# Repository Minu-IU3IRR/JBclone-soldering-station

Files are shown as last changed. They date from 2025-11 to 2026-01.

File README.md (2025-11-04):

# DIY Multi-Channel JBC-Compatible Soldering Station

A high-performance open hardware soldering station designed to support **JBC and other thermocouple-based soldering tips**.  
This project aims to deliver professional-grade thermal control and user experience at a fraction of the cost of a commercial JBC system.

---

## Overview

The system provides **multi-channel support**, each with independent temperature feedback loops based on PID control.  
It includes modular PCB designs, 3D-printable case that fits in a standard 200x200mm 3d printer, STM32F103 microcontroller, Nextion HMI interface

**Key features:**
- Multi-channel indipendent temperature control
- Compatible with any arbitrary tip, JBC or otherwise, as long as it uses a thermocouple
- PID temperature control with zero cross switching
- external EEprom stored calcibration and tuning  
- Nextion-based HMI for user interaction
- Fully open-source hardware and firmware

---
## Firmware Architecture

The firmware is structured into modules:

| Module | Description |
|---|---|
| **Heater/** | PID controller, temperature processing, and power control routines |
| **EEprom/** | Persistent storage for calibration and configuration |
| **Hardware_definition/** | Board pin mapping, timing constants, and I/O configuration |
| **display/** | Nextion display communication handler |
| **hartbeat/** | System heartbeat and status indicator |
| **Parser/** | Command parser for serial/HMI communication |

**PID Control:**  
The controller continuously adjusts heater drive based on thermocouple feedback.  
Parameters `Kp`, `Ki`, and `Kd` can be tuned at runtime through serial commands or tuning software.

**EEPROM Configuration:**  
All configuration data (tip profiles, PID tuning, calibration) is saved in EEPROM.  
On startup, the station loads the saved configuration automatically.

---

## Hardware Assembly

1. **PCBs:**  
   Fabricate the `mainboard` and `daughterboard` Gerbers (found under `/production/`).
2. **Mechanical design:**  
   View or download the CAD model on Onshape:  
   👉 [Onshape Assembly Model](https://cad.onshape.com/documents/a679f571d3dbe280f604253c/w/8a053e0b812f1b7821749418/e/78f31934af3d4bb4e1cbee4a)
3. **Transformer:**  
   Follow winding and connection details from the `transformer/` folder or pick a closely matched one (MUST HAVE INDIPENDENT WINDINGS FOR EACH OUTPUT)

---

## 🖥️ HMI Setup

1. Open `NX3224T024_hmi.HMI` in **Nextion Editor**.
2. Connect the display to the mainboard’s UART (`Serial1`, 115200 bps).
3. Upload the `.tft` file to the screen via SD card or serial upload or upload via SD-card, check Nextion documentation
5. The interface provides:
   - Channel selection  
   - Temperature setpoint entry  
   - Live tip temperature display

---

## Software Build

1. **Install [PlatformIO](https://platformio.org/).**
2. Open `Software/JBclone Firmware/` in VS Code.
3. Connect your STM32 board using an ST-link dongle.
4. Build and upload:
   ```bash
   pio run --target upload
   ```
5. The firmware will automatically initialize EEPROM and start monitoring the heater.

---

## Calibration & Tuning

- Refer to `cal and tuning table.ods` for measured offsets and recommended PID coefficients.  
- Store calibration through serial commands or via tuning software.  
- EEPROM ensures retention between power cycles.

---

## License

**Hardware (PCBs, transformer, mechanical design):**  
Released under the [CERN-OHL-P v2 License](https://ohwr.org/project/cernohl/wikis/Documents/CERN-OHL-version-2).  
You are free to use, modify, and distribute, provided attribution to the original project is maintained.  

**Firmware and software:**  
Released under the [MIT License](https://opensource.org/licenses/MIT).  

All content is provided **as-is** without any warranty or liability.  
Please include a reference to this repository when sharing or modifying the design.

---

## Credits

Project designed and developed by Manuel Minutello.  
Hardware and firmware are open for modification and improvement by the community.

---

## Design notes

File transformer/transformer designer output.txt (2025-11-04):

Transformer design
Sn (VA)                                  : 150.00
Efficiency (%)                           : 90.06
Total Power Loss (W)                     : 16.55
Total mass (kg)                          : 4.66
Core
|-design frequency (Hz):                 : 50.00
|-thickness (mm):                        : 55.00
|-mass (kg):                             : 4.04
|-Pfe (W):                               : 0.81
|-cross section area (cm^2):             : 22.00
|-V/turn:                                : 0.49
============================================================
Upper bobin
|-Primary Winding
|  |-Vn (V):                                  : 230.19
|  |-In (A):                                  : 0.65
|  |-Current density (A/mm^2):                : 2.09
|  |-Pcu (W):                                 : 2.30
|  |-N:                                       : 471
|  |-Wire total diameter (mm):                : 0.72
|  |-Wire conductor diameter (mm):            : 0.63
|  |-Wire length (m):                         : 98.31
|  |-Wire mass (kg):                          : 0.26
|  |-Resistance (ohms):                       : 5.424
|  |-Winding layers:                          : 13
|  |-Winding thickness (mm):                  : 9.36
|  |-insulation applied between layers:       : No
   **********************************************************
|-Mylar Tape, 3 wraps
|  |-total thickness (mm):                    : 0.30
   **********************************************************
|-AM120_1
|  |-Vn (V):                                  : 10.26
|  |-In (A):                                  : 4.75
|  |-Current density (A/mm^2):                : 3.09
|  |-Pcu (W):                                 : 1.24
|  |-N:                                       : 21
|  |-Wire total diameter (mm):                : 1.53
|  |-Wire conductor diameter (mm):            : 1.40
|  |-Wire length (m):                         : 4.93
|  |-Wire mass (kg):                          : 0.06
|  |-Resistance (ohms):                       : 0.055
|  |-Full load output voltage (V):            : 9.84
|  |-Winding layers:                          : 2
|  |-Winding thickness (mm):                  : 3.06
|  |-insulation applied between layers:       : No
   **********************************************************
|-Mylar Tape, 3 wraps
|  |-total thickness (mm):                    : 0.30
   **********************************************************
No errors
Bobin occupancy (%):                     : 72.9
============================================================
Lower bobin
|-AM120_2
|  |-Vn (V):                                  : 10.26
|  |-In (A):                                  : 4.75
|  |-Current density (A/mm^2):                : 3.09
|  |-Pcu (W):                                 : 1.04
|  |-N:                                       : 21
|  |-Wire total diameter (mm):                : 1.53
|  |-Wire conductor diameter (mm):            : 1.40
|  |-Wire length (m):                         : 4.12
|  |-Wire mass (kg):                          : 0.05
|  |-Resistance (ohms):                       : 0.046
|  |-Full load output voltage (V):            : 9.89
|  |-Winding layers:                          : 2
|  |-Winding thickness (mm):                  : 3.06
|  |-insulation applied between layers:       : No
   **********************************************************
|-Mylar Tape, 3 wraps
|  |-total thickness (mm):                    : 0.30
   **********************************************************
|-T245
|  |-Vn (V):                                  : 20.04
|  |-In (A):                                  : 7.40
|  |-Current density (A/mm^2):                : 4.81
|  |-Pcu (W):                                 : 5.33
|  |-N:                                       : 41
|  |-Wire total diameter (mm):                : 1.53
|  |-Wire conductor diameter (mm):            : 1.40
|  |-Wire length (m):                         : 8.72
|  |-Wire mass (kg):                          : 0.11
|  |-Resistance (ohms):                       : 0.097
|  |-Full load output voltage (V):            : 19.01
|  |-Winding layers:                          : 3
|  |-Winding thickness (mm):                  : 4.59
|  |-insulation applied between layers:       : No
   **********************************************************
|-Mylar Tape, 3 wraps
|  |-total thickness (mm):                    : 0.30
   **********************************************************
|-DS360 (2x10V)
|  |-Vn (V):                                  : 20.04
|  |-In (A):                                  : 7.40
|  |-Current density (A/mm^2):                : 4.81
|  |-Pcu (W):                                 : 5.82
|  |-N:                                       : 41
|  |-Wire total diameter (mm):                : 1.53
|  |-Wire conductor diameter (mm):            : 1.40
|  |-Wire length (m):                         : 9.52
|  |-Wire mass (kg):                          : 0.13
|  |-Resistance (ohms):                       : 0.106
|  |-Full load output voltage (V):            : 18.94
|  |-Winding layers:                          : 3
|  |-Winding thickness (mm):                  : 4.59
|  |-insulation applied between layers:       : No
   **********************************************************
|-Mylar Tape, 3 wraps
|  |-total thickness (mm):                    : 0.30
   **********************************************************
No errors
Bobin occupancy (%):                     : 73.6
============================================================

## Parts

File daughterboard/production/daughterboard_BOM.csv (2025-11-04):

Reference | Value | Footprint | Datasheet | digikey | Qty
C1, C3 | 4.7n | Capacitor_SMD:C_0805_2012Metric_Pad1.18x1.45mm_HandSolder | https://search.murata.co.jp/Ceramy/image/img/A01X/G101/ENG/GRM2195C1H472JA01-01A.pdf | 490-1634-1-ND | 2
D1, D3 | LED | LED_SMD:LED_0805_2012Metric_Pad1.15x1.40mm_HandSolder | https://www.qt-brightek.com/datasheet/QBLP631-IG5.pdf | 1516-QBLP631-IG5CT-ND | 2
D2 | BAT54S | Package_TO_SOT_SMD:SOT-23 | https://www.diodes.com/assets/Datasheets/BAT54_A_C_S.pdf | BAT54S-FDICT-ND | 1
J1 | BTN | Connector_PinHeader_2.54mm:PinHeader_1x03_P2.54mm_Vertical | https://cdn.amphenol-cs.com/media/wysiwyg/files/documentation/datasheet/boardwiretoboard/bwb_econostik_254headers.pdf | 10129378-903004BLF-ND | 1
J2 | recepticle |  | https://www.phoenixcontact.com/en-us/products/pcb-plug-mstb-25-6-st-508-1757051?type=pdf | 277-1015-ND | 1
J3, J4 | support | 01_custom footprint:AMT0440051DB | https://www.anytek.com.cn/Upload/AMT0440051DB0000G-67c577521b2b436595c111b9c96188af.pdf | 1818-AMT0440051DB0000G-ND | 2
J5 | IRON | Connector_Phoenix_MSTB:PhoenixContact_MSTB_2,5_6-GF-5,08_1x06_P5.08mm_Horizontal_ThreadedFlange | https://www.phoenixcontact.com/us/products/1759059/pdf | 277-1099-ND | 1
J6 | interface | Connector_PinHeader_2.54mm:PinHeader_2x03_P2.54mm_Horizontal | https://mm.digikey.com/Volume0/opasdata/d220001/medias/docus/5335/PHED-RSzzzG1ABOGA-C006_Drawing.pdf | 4324-PHED-RS006G1ABOGA-C006-ND | 1
JP1 | TCgain | Jumper:SolderJumper-2_P1.3mm_Open_RoundedPad1.0x1.5mm | NA | NA | 1
Q1 | MMBT3904 | Package_TO_SOT_SMD:SOT-23 | https://www.mccsemi.com/pdf/Products/MMBT3904(SOT-23).pdf | MMBT3904TPMSCT-ND | 1
Q3, Q4 | DMT68M8LSS | Package_SO:SO-8_3.9x4.9mm_P1.27mm | https://www.diodes.com/assets/Datasheets/DMT68M8LSS.pdf | 31-DMT68M8LSS-13CT-ND | 2
R1, R3, R7, R8, R14, R16 | 10k | Resistor_SMD:R_0805_2012Metric_Pad1.20x1.40mm_HandSolder | https://industrial.panasonic.com/ww/products/pt/general-purpose-chip-resistors/models/ERJ6GEYJ103V | P10KACT-ND | 6
R2, R9, R10 | 1.5k | Resistor_SMD:R_0805_2012Metric_Pad1.20x1.40mm_HandSolder | https://www.yageo.com/upload/media/product/products/datasheet/rchip/PYu-RC_Group_51_RoHS_L_12.pdf | 311-1.5KARCT-ND | 3
R4 | 330R | Resistor_SMD:R_0805_2012Metric_Pad1.20x1.40mm_HandSolder | https://industrial.panasonic.com/ww/products/pt/general-purpose-chip-resistors/models/ERJ6GEYJ331V | P330ACT-ND | 1
R5 | 100k | Resistor_SMD:R_0805_2012Metric_Pad1.20x1.40mm_HandSolder | https://industrial.panasonic.com/ww/products/pt/general-purpose-chip-resistors/models/ERJ6GEYJ104V | P100KACT-ND | 1
R6 | 590k | Resistor_SMD:R_0805_2012Metric_Pad1.20x1.40mm_HandSolder | https://industrial.panasonic.com/cdbs/www-data/pdf/RDM0000/AOA0000C307.pdf | P590KDACT-ND | 1
R11, R12 | 10k | Resistor_SMD:R_0805_2012Metric | https://industrial.panasonic.com/ww/products/pt/general-purpose-chip-resistors/models/ERJ6GEYJ103V | P10KACT-ND | 2
U1, U3 | LMV321 | Package_TO_SOT_SMD:SOT-23-5_HandSoldering | https://rocelec.widen.net/view/pdf/hsbslfymvc/slos263w.pdf?t.download=true&u=5oefqw | 296-9567-1-ND | 2
U2 | VOM1271T | 01_custom footprint:SOP-4 | https://www.vishay.com/docs/83469/vom1271.pdf | VOM1271TCT-ND | 1
U4 | TLP290 | Package_SO:SOP-4_4.4x2.6mm_P1.27mm | https://toshiba.semicon-storage.com/info/docget.jsp?did=12882&prodName=TLP290 | TLP290(GB-TPSECT-ND | 1
U6 | INA186A4 | Package_TO_SOT_SMD:SOT-23-5 | https://www.ti.com/lit/ds/symlink/ina186-q1.pdf | 296-INA186A4QDBVRQ1CT-ND | 1

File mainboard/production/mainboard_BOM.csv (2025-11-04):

Reference | Value | Footprint | Datasheet | digikey | Qty
C1, C6, C12, C13 | 100n | Capacitor_SMD:C_0805_2012Metric_Pad1.18x1.45mm_HandSolder | https://mm.digikey.com/Volume0/opasdata/d220001/medias/docus/609/CL21B104KBCNNN_Spec.pdf | 1276-1003-1-ND | 4
C2, C3, C7, C17 | 10uF | Capacitor_SMD:C_0805_2012Metric_Pad1.18x1.45mm_HandSolder | https://mm.digikey.com/Volume0/opasdata/d220001/medias/docus/609/CL21A106KOQNNNE_Spec.pdf | 1276-1096-1-ND | 4
D1 | LED | LED_SMD:LED_0805_2012Metric_Pad1.15x1.40mm_HandSolder | https://www.qt-brightek.com/datasheet/QBLP631-IG5.pdf | 1516-QBLP631-IG5CT-ND | 1
D2-D5 | BAT54S | Package_TO_SOT_SMD:SOT-23 | https://www.diodes.com/assets/Datasheets/BAT54_A_C_S.pdf | BAT54S-FDICT-ND | 4
H1-H3 | MountingHole | MountingHole:MountingHole_3.2mm_M3 | N/A | N/A | 3
J1 | HMI | Connector_PinHeader_2.54mm:PinHeader_1x04_P2.54mm_Vertical | https://cdn.amphenol-cs.com/media/wysiwyg/files/drawing/g800wxxxxxxeu_1.pdf | 664-G800W304018EU-ND | 1
J2, J4, J5, J10 | PB_2 | 01_ProjectFootprint:DaughterBoard | https://www.we-online.com/components/products/datasheet/61300621821.pdf | 732-61300621821-ND | 4
J3 | USB | Connector_PinHeader_2.54mm:PinHeader_1x03_P2.54mm_Vertical | https://cdn.amphenol-cs.com/media/wysiwyg/files/drawing/g800wxxxxxxeu_1.pdf | 664-G800W305018EU-ND | 1
J6 | GPIO | Connector_PinSocket_2.54mm:PinSocket_2x04_P2.54mm_Vertical | https://www.we-online.com/components/products/datasheet/61300621821.pdf | 732-61300621821-ND | 1
J7 | STlink | Connector_PinHeader_2.54mm:PinHeader_1x03_P2.54mm_Vertical | https://cdn.amphenol-cs.com/media/wysiwyg/files/drawing/g800wxxxxxxeu_1.pdf | 664-G800W305018EU-ND | 1
J8 | PWR | TerminalBlock_Phoenix:TerminalBlock_Phoenix_MKDS-1,5-3-5.08_1x03_P5.08mm_Horizontal | https://www.phoenixcontact.com/us/products/1715734/pdf | 277-1264-ND | 1
J9 | STAND | Connector_PinHeader_2.54mm:PinHeader_1x03_P2.54mm_Vertical | https://cdn.amphenol-cs.com/media/wysiwyg/files/drawing/g800wxxxxxxeu_1.pdf | 664-G800W305018EU-ND | 1
PS1 | IRM-02-5 | Converter_ACDC:Converter_ACDC_MeanWell_IRM-02-xx_THT | https://www.meanwell.com/Upload/PDF/IRM-02/IRM-02-SPEC.PDF | 1866-3009-ND | 1
Q1 | MMBT3904 | Package_TO_SOT_SMD:SOT-23 | https://www.mccsemi.com/pdf/Products/MMBT3904(SOT-23).pdf | MMBT3904TPMSCT-ND | 1
R1, R4-R8, R11, R14, R15 | 10k | Resistor_SMD:R_0805_2012Metric_Pad1.20x1.40mm_HandSolder | https://industrial.panasonic.com/ww/products/pt/general-purpose-chip-resistors/models/ERJ6GEYJ103V | P10KACT-ND | 9
R2, R3, R9, R10, R13 | 1.5k | Resistor_SMD:R_0805_2012Metric_Pad1.20x1.40mm_HandSolder | https://www.yageo.com/upload/media/product/products/datasheet/rchip/PYu-RC_Group_51_RoHS_L_12.pdf | 311-1.5KARCT-ND | 5
R12 | 100k | Resistor_SMD:R_0805_2012Metric_Pad1.20x1.40mm_HandSolder | https://industrial.panasonic.com/ww/products/pt/general-purpose-chip-resistors/models/ERJ6GEYJ104V | P100KACT-ND | 1
R23, R25 | 590k | Resistor_SMD:R_0805_2012Metric_Pad1.20x1.40mm_HandSolder | https://industrial.panasonic.com/cdbs/www-data/pdf/RDM0000/AOA0000C307.pdf | P590KDACT-ND | 2
RV1 | 270KD07 | Varistor:RV_Disc_D7mm_W4.8mm_P5mm | https://www.yageo.com/upload/media/product/app/datasheet/cpc/mov/7d.pdf | 13-270KD07-ND | 1
U1 | STM32F103C8T6 | Package_QFP:LQFP-48_7x7mm_P0.5mm | https://www.st.com/resource/en/datasheet/stm32f103cb.pdf | 497-17666-1-ND | 1
U2, U5-U7 | LMV321 | Package_TO_SOT_SMD:SOT-23-5_HandSoldering | https://rocelec.widen.net/view/pdf/hsbslfymvc/slos263w.pdf?t.download=true&u=5oefqw | 296-9567-1-ND | 4
U3 | TPS22919DCKR | Package_TO_SOT_SMD:SOT-23-6_Handsoldering | https://www.ti.com/lit/ds/symlink/tps22919.pdf | 296-TPS22919DCKRCT-ND | 1
U4 | 24FC04HT | Package_TO_SOT_SMD:SOT-23-5_HandSoldering | https://ww1.microchip.com/downloads/en/DeviceDoc/24AA04H-24LC04BH-24FC04H-4K-I2C-Serial-EEPROM-With-Half-Array-Write-Protect-20002119C.pdf | 24FC04HT-I/OTCT-ND | 1
U10 | LD1117DT33 | Package_TO_SOT_SMD:TO-252-2 | https://www.st.com/content/ccc/resource/technical/document/datasheet/99/3b/7d/91/91/51/4b/be/CD00000544.pdf/files/CD00000544.pdf/jcr:content/translations/en.C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 | 497-1235-1-ND | 1
Y2 | 8MHz | Crystal:Resonator_SMD_Murata_CSTxExxV-3Pin_3.0x1.1mm_HandSoldering | https://www.murata.com/en/products/productdata/8801161740318/SPEC-CSTNE8M00G550000R0.pdf | 490-17958-1-ND | 1

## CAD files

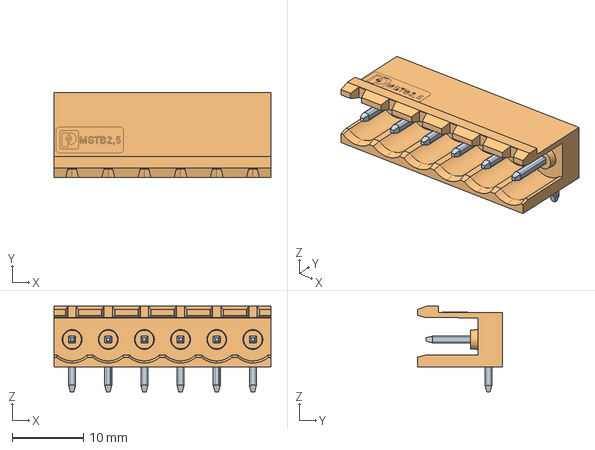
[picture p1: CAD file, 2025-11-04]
mainboard/modelli 3d/1759059.stp
30.5 x 12.0 x 12.1 mm

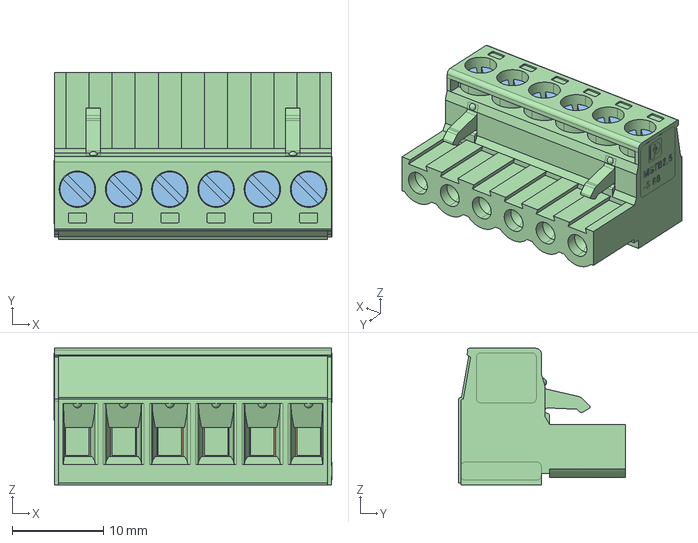
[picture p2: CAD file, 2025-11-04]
mainboard/modelli 3d/1757051.stp
30.5 x 18.3 x 15.0 mm

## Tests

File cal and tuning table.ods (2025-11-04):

C245 thermocouple measurement
index | TC dV [uV] | Meas [C°] | S[uV/C°]
1 | 0 | 20 | 0.00
2 | 1500 | 96 | 15.63
3 | 3000 | 154 | 19.48
4 | 4000 | 191.5 | 20.89
5 | 5000 | 235 | 21.28
6 | 6000 | 262 | 22.90
7 | 7000 | 310 | 22.58
8 | 9000 | 372.5 | 24.16
9 | 10200 | 423 | 24.11
10 | 11100 | 458 | 24.24
tuning
Kp | 6
Ki | 0.5
Kd | 0
DS360
index | TC dV [uV] | Meas [C°] | S[uV/C°]
1 | 0 | 25 | 0.00
2 | 500 | 117 | 4.27
3 | 900 | 163 | 5.52
4 | 1300 | 205 | 6.34
5 | 2000 | 279 | 7.17
6 | 2300 | 306 | 7.52
7 | 2600 | 336 | 7.74
8 | 2900 | 365 | 7.95
9 | 3500 | 419 | 8.35
10 | 3800 | 450 | 8.44
tuning
Kp | 15
Ki | 1
Kd | 0
AM120
index | TC dV [uV] | Meas [C°] | S[uV/C°]
1 | 0 | 25 | 0.00
2 | 500 | 95 | 5.26
3 | 800 | 130 | 6.15
4 | 1100 | 160 | 6.88
5 | 1500 | 198 | 7.58
6 | 1800 | 222 | 8.11
7 | 2500 | 280 | 8.93
8 | 3000 | 317 | 9.46
9 | 3500 | 357 | 9.80
10 | 4300 | 416 | 10.34
tuning
Kp | 10
Ki | 0.4
Kd | 0

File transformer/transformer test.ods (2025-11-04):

winding turn ratio test
Open circuit test |  |  |  |  |  |  | winding ratios
V1 | AM120_1 | AM120_2 | C250 | DS360 |  |  | K1-1 | K1-2 | K1-3 | K1-4
19.91 | 0.8322 | 0.833 | 1.746 |  |  |  | 23.925 | 23.902 | 11.403
42.3 | 1.76 | 1.77 | 3.71 |  |  |  | 24.034 | 23.898 | 11.402
62.2 | 2.6 | 2.6 | 5.46 |  |  |  | 23.923 | 23.923 | 11.392
78.6 | 3.28 | 3.28 | 6.88 | 6.74 |  |  | 23.963 | 23.963 | 11.424 | 11.662
94.4 | 3.91 |  | 8.3 | 8.11 |  |  | 24.143 |  | 11.373 | 11.640
119 | 4.95 |  | 10.4 | 10.15 |  |  | 24.040 |  | 11.442 | 11.724
146 | 6.098 |  | 12.8 | 12.5 |  |  | 23.942 |  | 11.406 | 11.680
168 | 7.02 |  | 14.75 | 14.4 |  |  | 23.932 |  | 11.390 | 11.667
188 | 7.87 |  | 16.5 | 16.1 |  |  | 23.888 |  | 11.394 | 11.677
211 | 8.8 |  | 18.45 | 18 |  |  | 23.977 |  | 11.436 | 11.722
 |  |  |  |  |  |  | avg
 |  |  |  |  |  |  | 23.977 | 23.922 | 11.406 | 11.682
 |  |  |  |  | nominal voltages | Vin | AM120_1 | AM120_2 | C250 | DS360
 |  |  |  |  |  | 230 | 9.593 | 9.615 | 20.164 | 19.689
Primary saturation curent test
I1 [mA] | V1 [V[
0.5 | 22.3
2.5 | 51.3
7.5 | 75
6.7 | 102
9 | 131.2
11 | 156
19.3 | 189
39 | 208
70 | 233
120 | 260

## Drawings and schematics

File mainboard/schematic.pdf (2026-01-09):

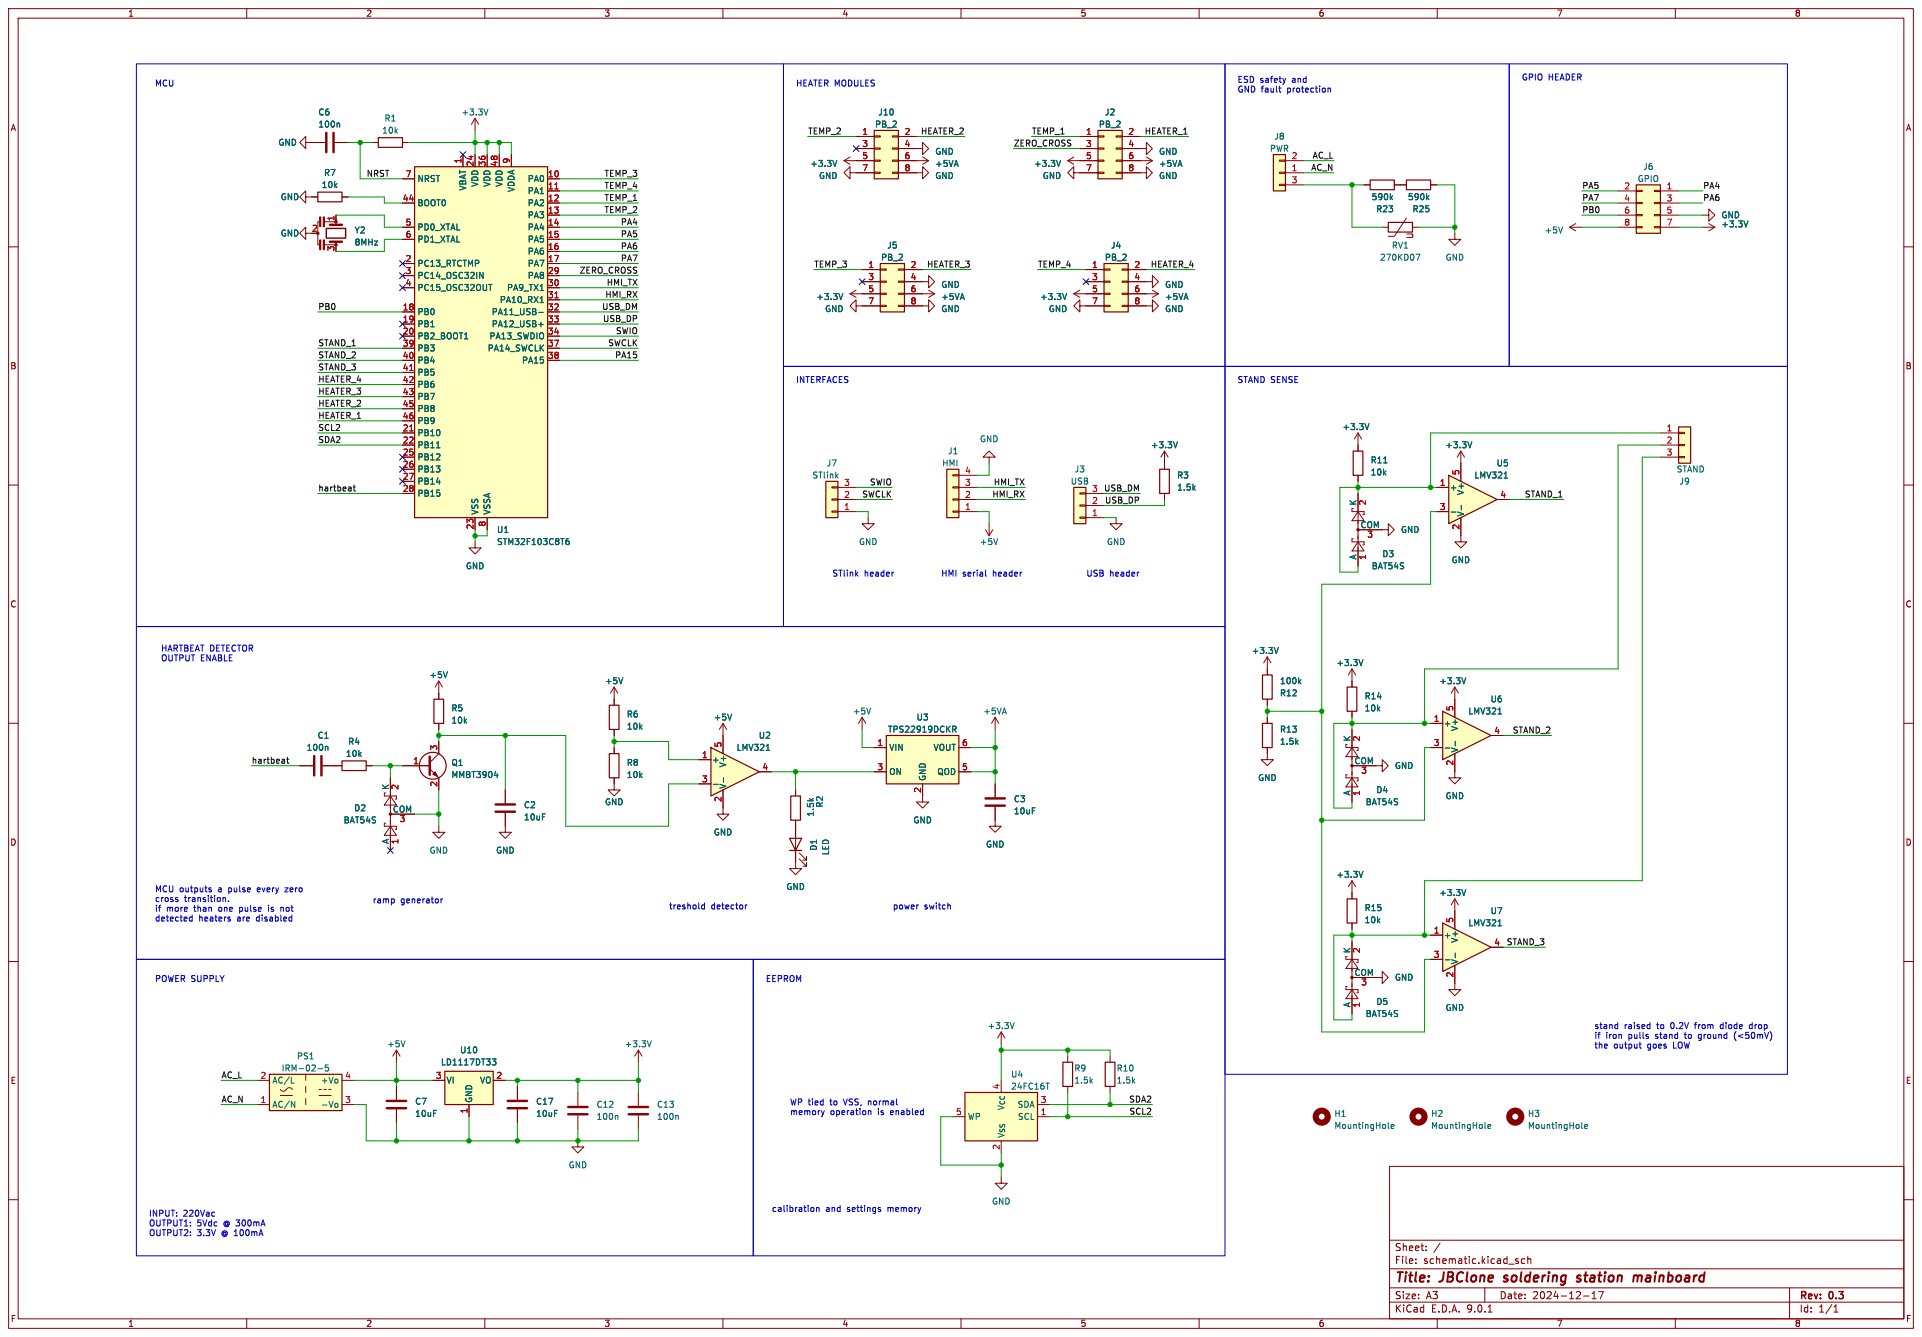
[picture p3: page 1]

ESD safety and GND fault protection

1 VDD 24 VSS 23 VDD 36 VSSA

HMI serial header POWER SUPPLY HARTBEAT DETECTOR OUTPUT ENABLE

2 VOUT 6 QOD 5 GND R2 1.5k D1 LED

H3 MountingHole GND GND GND

MCU outputs a pulse every zero
cross transition.

stand raised to 0.2V from diode drop
if iron pulls stand to ground (<50mV)
the output goes LOW

File: schematic.kicad_sch Sheet: /
Id: 1/1 Title: JBClone soldering station mainboard

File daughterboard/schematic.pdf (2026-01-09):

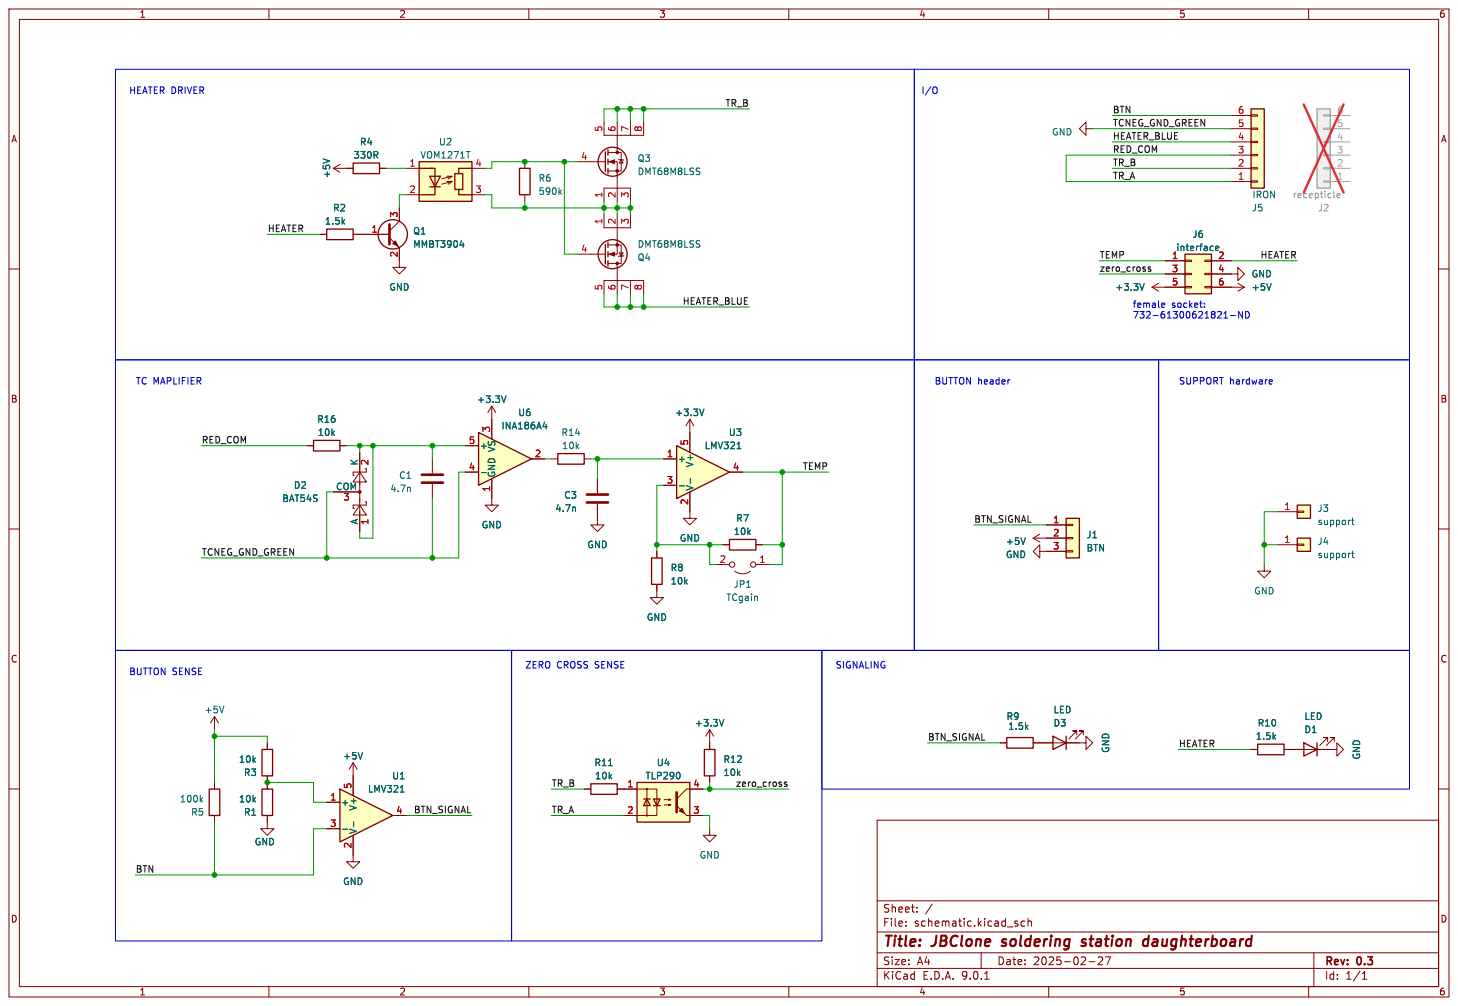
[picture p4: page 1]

Id: 1/1 Title: JBClone soldering station daughterboard

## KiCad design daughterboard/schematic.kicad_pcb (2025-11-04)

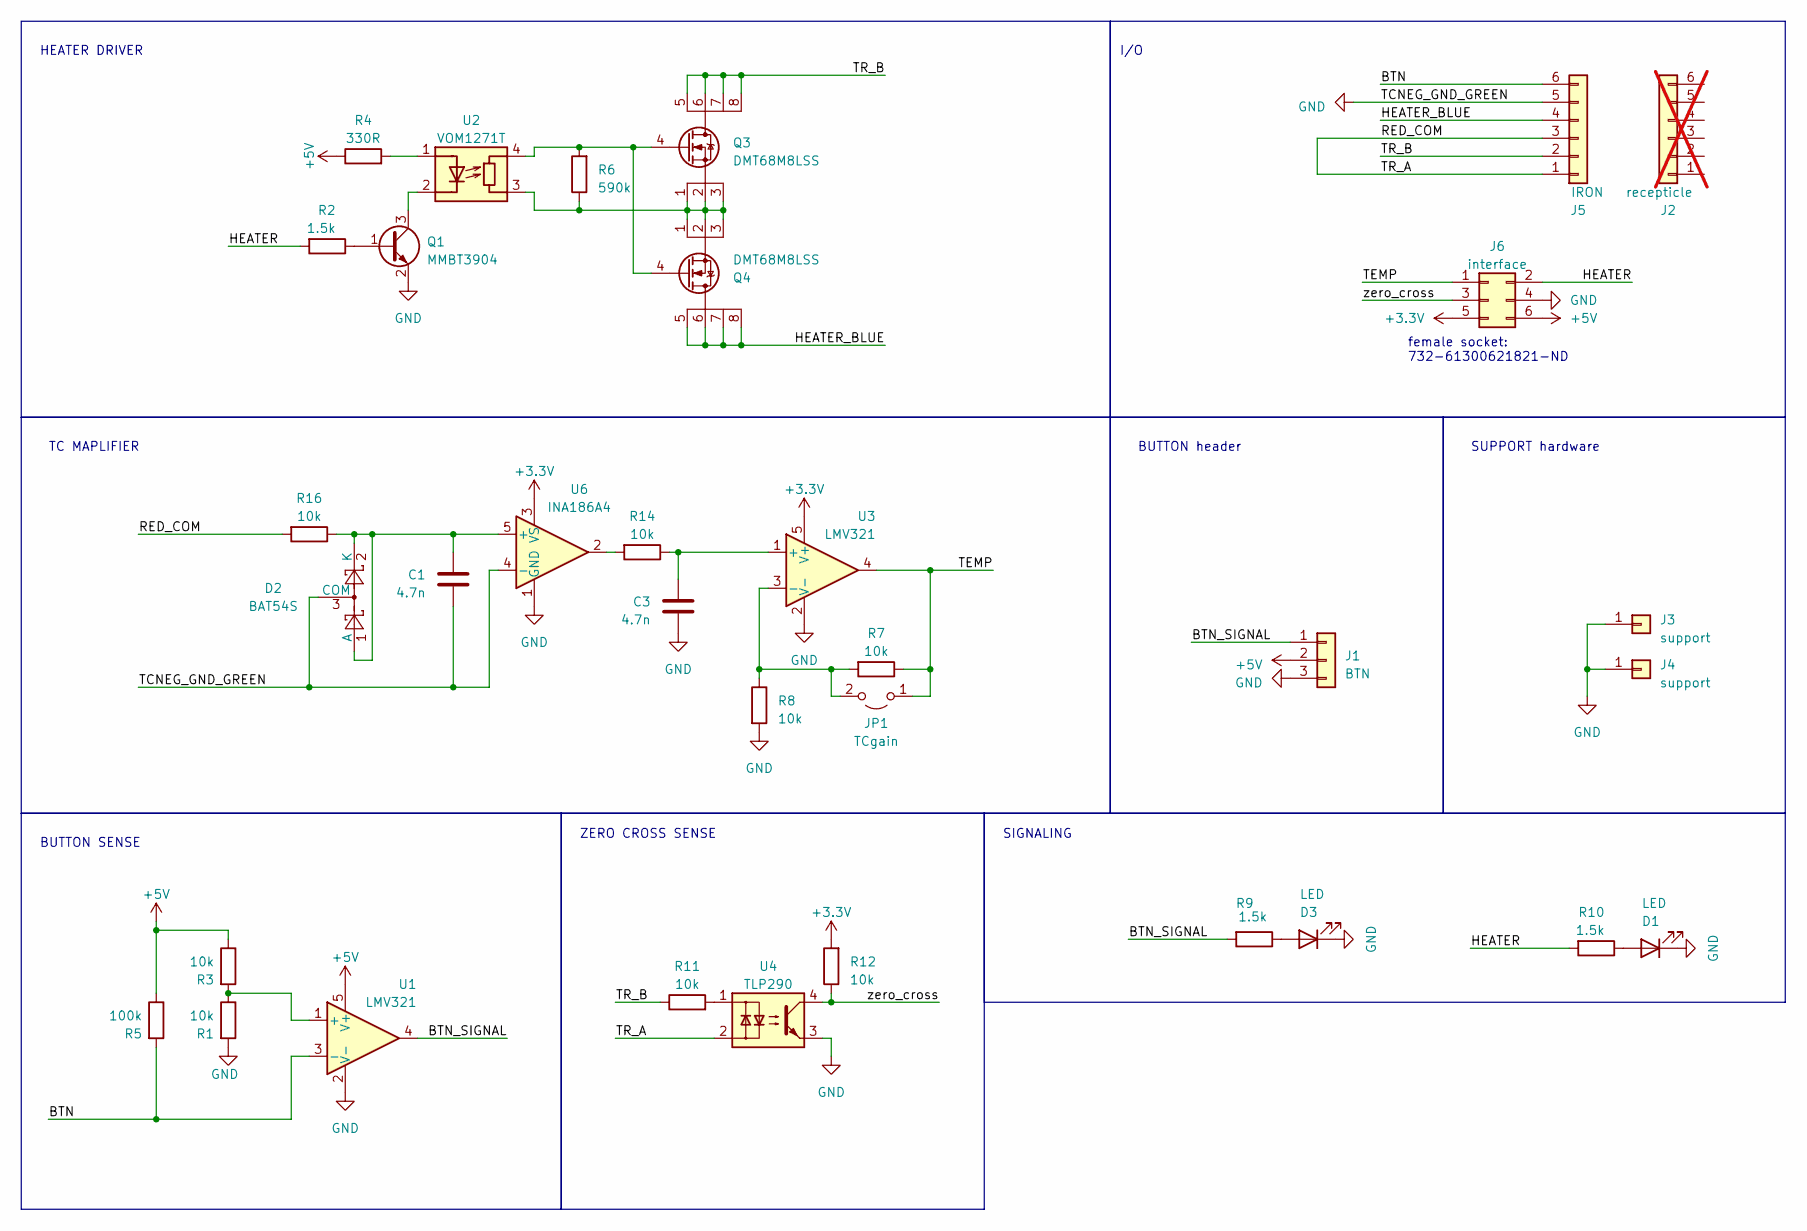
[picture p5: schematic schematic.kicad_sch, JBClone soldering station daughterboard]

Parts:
C1, C3: 4.7n; C_0805_2012Metric_Pad1.18x1.45mm_HandSolder; digikey 490-1634-1-ND
D1, D3: LED; LED_0805_2012Metric_Pad1.15x1.40mm_HandSolder; digikey 1516-QBLP631-IG5CT-ND
D2: BAT54S; SOT-23; digikey BAT54S-FDICT-ND
J1: BTN; PinHeader_1x03_P2.54mm_Vertical; digikey 10129378-903004BLF-ND
J2: recepticle; digikey 277-1015-ND; not fitted
J3, J4: support; AMT0440051DB; digikey 1818-AMT0440051DB0000G-ND
J5: IRON; PhoenixContact_MSTB_2,5_6-GF-5,08_1x06_P5.08mm_Horizontal_T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; digikey 277-1099-ND
J6: interface; PinHeader_2x03_P2.54mm_Horizontal; digikey 4324-PHED-RS006G1ABOGA-C006-ND
JP1: TCgain; SolderJumper-2_P1.3mm_Open_RoundedPad1.0x1.5mm; digikey NA
Q1: MMBT3904; SOT-23; digikey MMBT3904TPMSCT-ND
Q3, Q4: DMT68M8LSS; SO-8_3.9x4.9mm_P1.27mm; digikey 31-DMT68M8LSS-13CT-ND
R1, R3, R7, R8, R14, R16: 10k; R_0805_2012Metric_Pad1.20x1.40mm_HandSolder; digikey P10KACT-ND
R2, R9, R10: 1.5k; R_0805_2012Metric_Pad1.20x1.40mm_HandSolder; digikey 311-1.5KARCT-ND
R4: 330R; R_0805_2012Metric_Pad1.20x1.40mm_HandSolder; digikey P330ACT-ND
R5: 100k; R_0805_2012Metric_Pad1.20x1.40mm_HandSolder; digikey P100KACT-ND
R6: 590k; R_0805_2012Metric_Pad1.20x1.40mm_HandSolder; digikey P590KDACT-ND
R11, R12: 10k; R_0805_2012Metric; digikey P10KACT-ND
U1, U3: LMV321; SOT-23-5_HandSoldering; digikey 296-9567-1-ND
U2: VOM1271T; SOP-4; digikey VOM1271TCT-ND
U4: TLP290; SOP-4_4.4x2.6mm_P1.27mm; digikey TLP290(GB-TPSECT-ND
U6: INA186A4; SOT-23-5; digikey 296-INA186A4QDBVRQ1CT-ND

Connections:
+3.3V: J6.5, R12.2, U3.5 (V+), U6.3 (VS)
+5V: J1.2, J6.6, R3.1, R4.1, R5.1, U1.5 (V+)
/BTN: J5.6, R5.2, U1.3 (-)
/BTN_SIGNAL: J1.1, R9.2, U1.4
/HEATER: J6.2, R2.2, R10.2
/HEATER_BLUE: J5.4, Q4.5 (D), Q4.6 (D), Q4.7 (D), Q4.8 (D)
/RED_COM: J5.1, J5.3, R16.2, U4.2
/TEMP: J6.1, JP1.1 (A), R7.1, U3.4
/TR_B: J5.2, Q3.5 (D), Q3.6 (D), Q3.7 (D), Q3.8 (D), R11.1
/zero_cross: J6.3, R12.1, U4.4
GND: C1.2, C3.2, D1.1 (K), D2.3 (COM), D3.1 (K), J1.3, J3.1, J4.1, J5.5, J6.4, Q1.2 (E), R1.2, R8.2, U1.2 (V-), U3.2 (V-), U4.3, U6.1 (GND), U6.4 (-)
unnamed: D1.2 (A), R10.1
unnamed: C1.1, D2.1 (A), D2.2 (K), R16.1, U6.5 (+)
unnamed: D3.2 (A), R9.1
unnamed: JP1.2 (B), R7.2, R8.1, U3.3 (-)
unnamed: Q1.1 (B), R2.1
unnamed: Q1.3 (C), U2.2 (K)
unnamed: Q3.1 (D), Q3.2 (D), Q3.3 (G), Q4.1 (D), Q4.2 (D), Q4.3 (G), R6.1, U2.3 (R)
unnamed: Q3.4 (S), Q4.4 (S), R6.2, U2.4 (R)
unnamed: R11.2, U4.1
unnamed: R14.2, U6.2
unnamed: R1.1, R3.2, U1.1 (+)
unnamed: R4.2, U2.1 (A)
unnamed: C3.1, R14.1, U3.1 (+)

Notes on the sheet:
HEATER DRIVER
SIGNALING
female socket: 732-61300621821-ND
I/O
SUPPORT hardware
TC MAPLIFIER
BUTTON SENSE
ZERO CROSS SENSE
BUTTON header

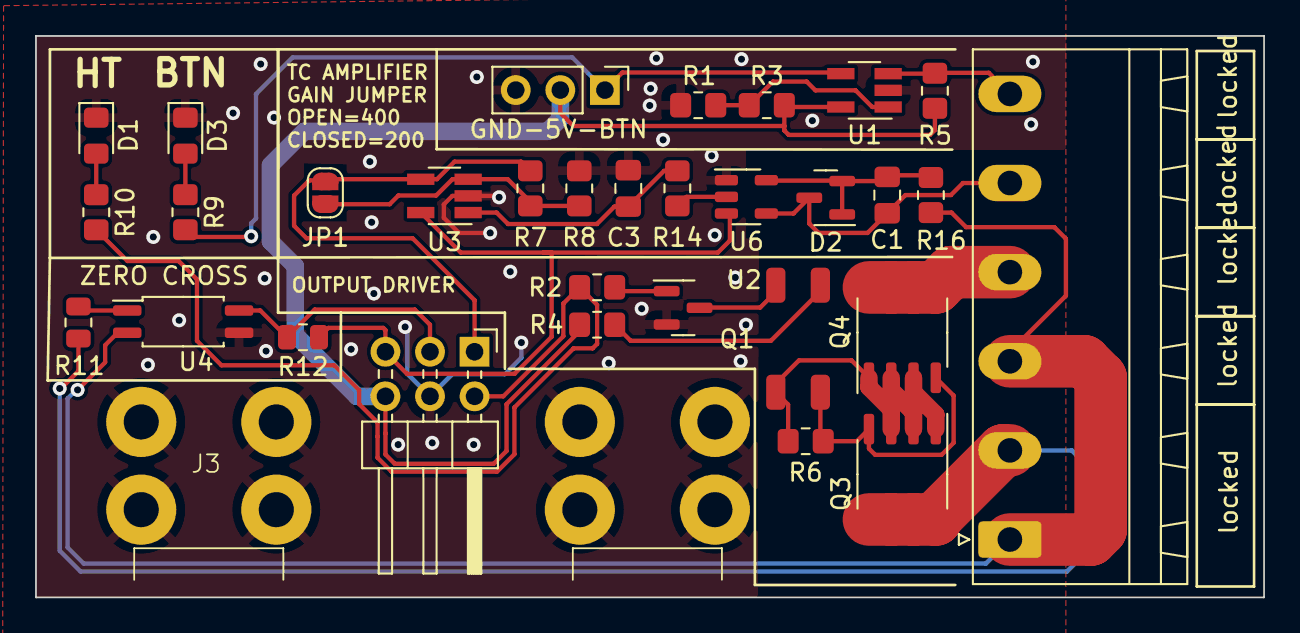
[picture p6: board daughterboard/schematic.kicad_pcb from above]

Board: 2 copper layers, 70.0 x 32.0 mm, 33 parts (0 on the bottom side), 24 nets.

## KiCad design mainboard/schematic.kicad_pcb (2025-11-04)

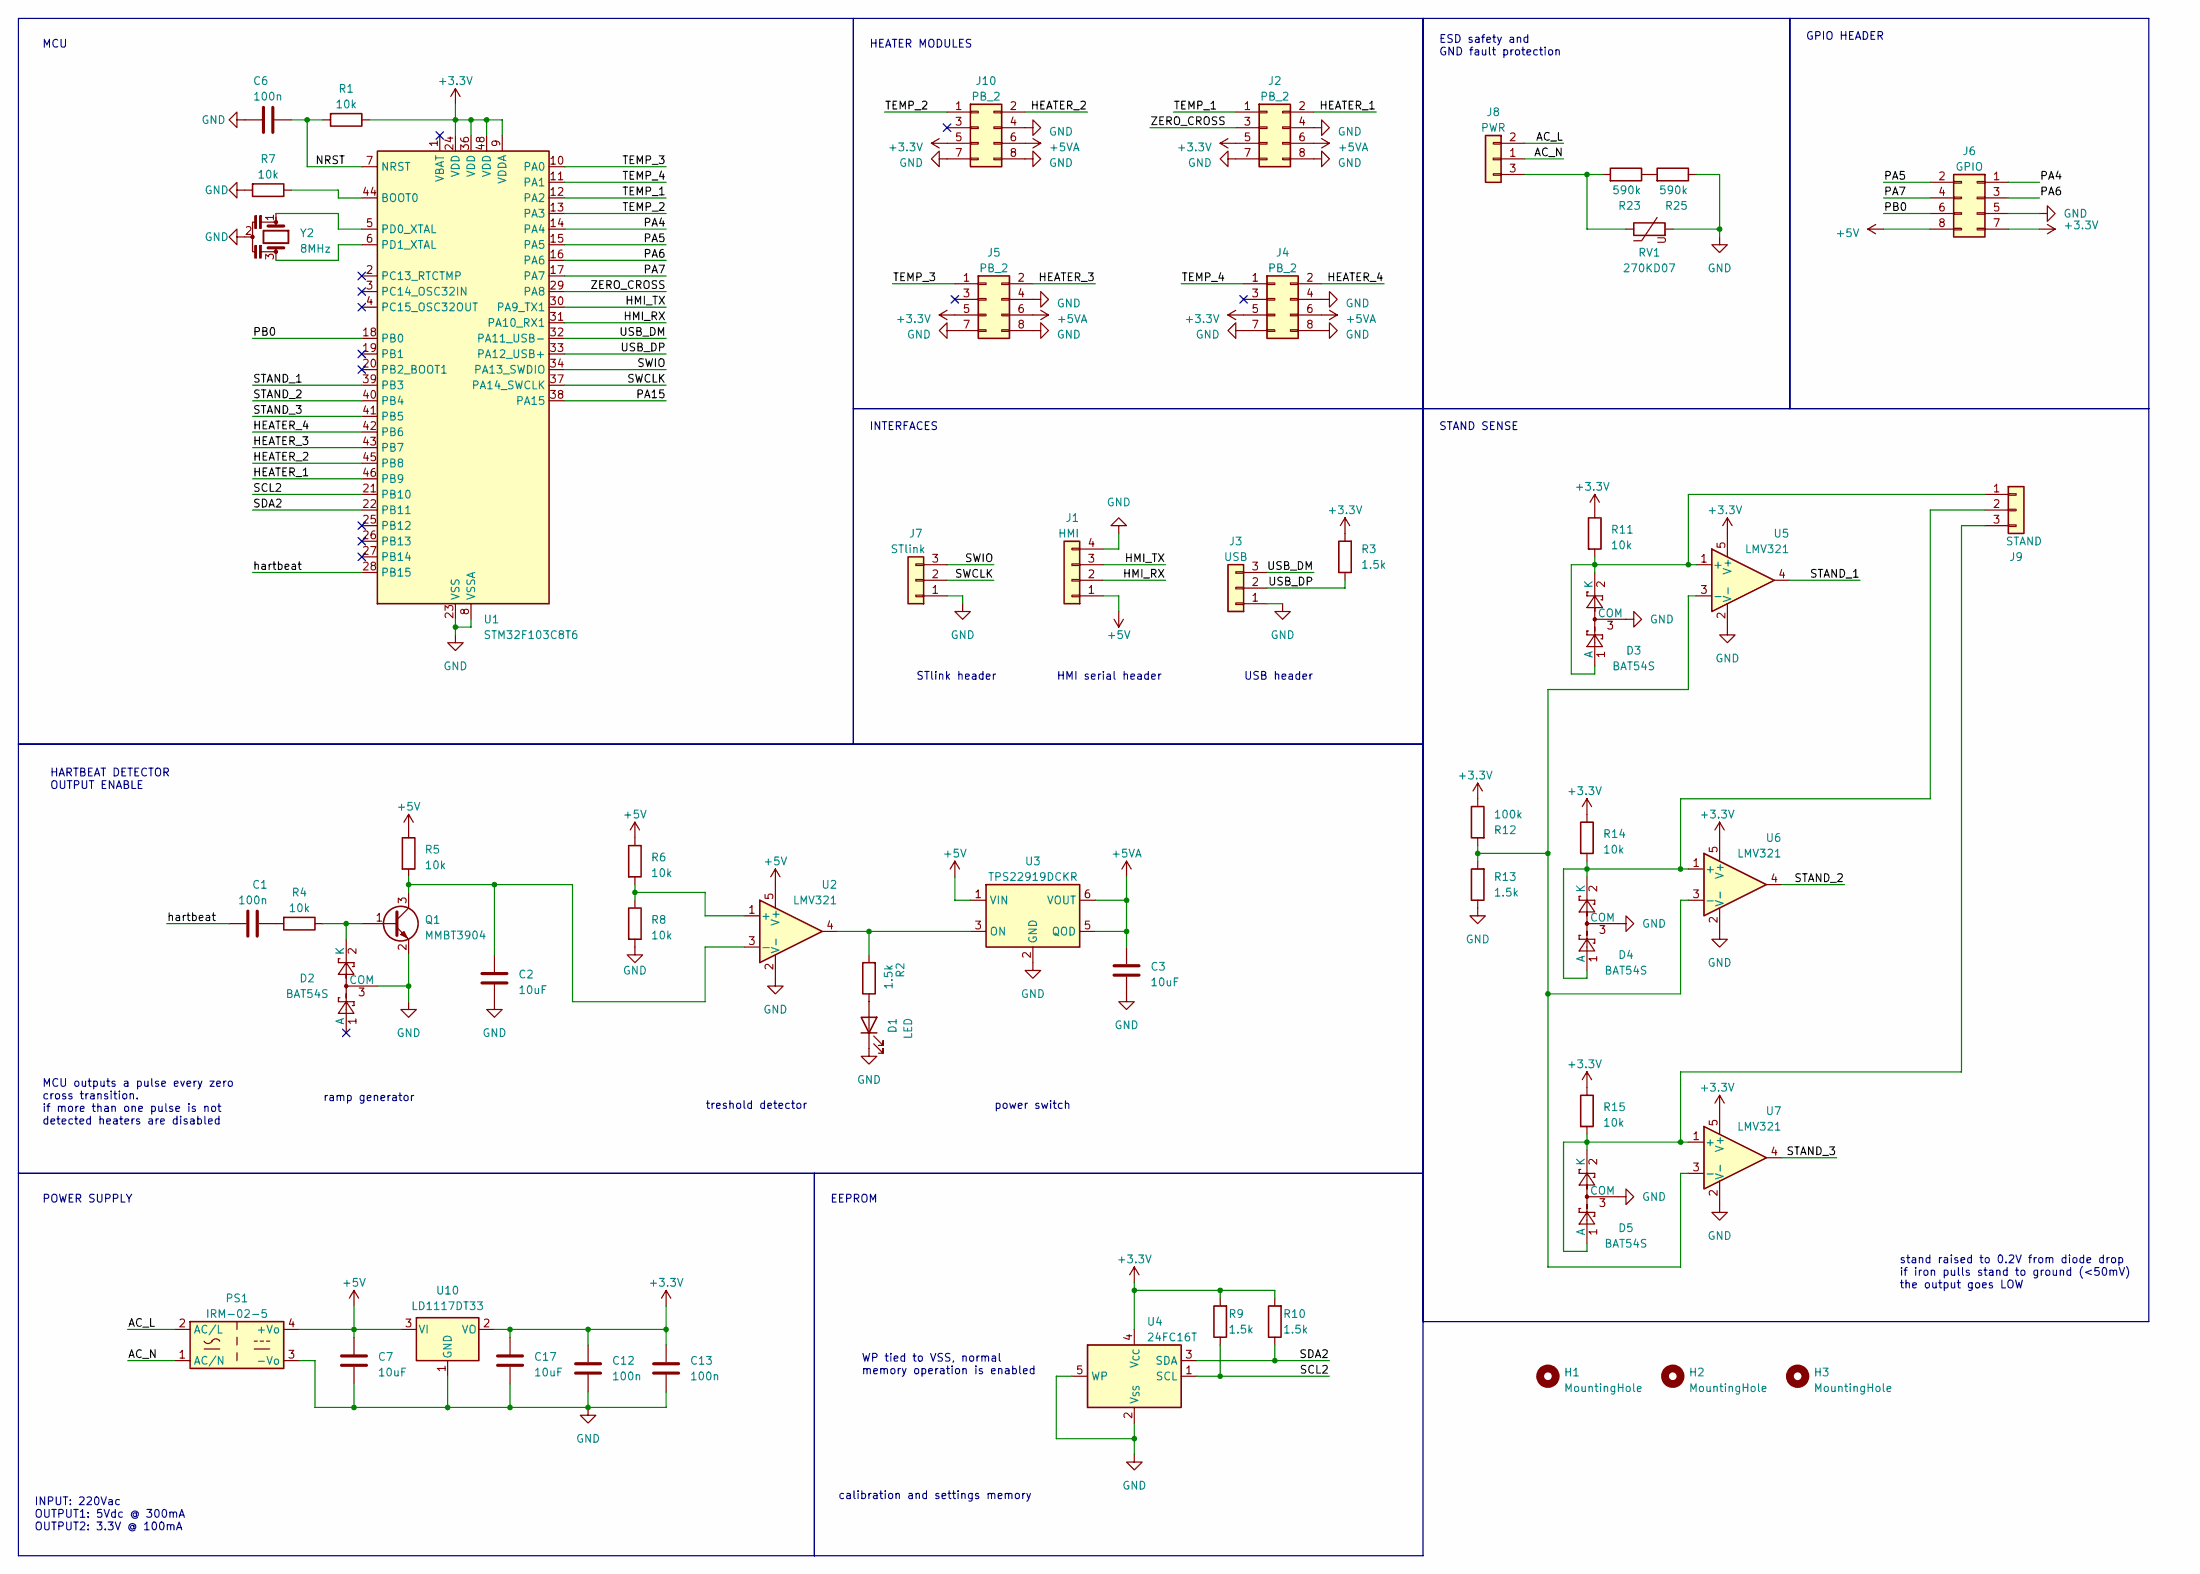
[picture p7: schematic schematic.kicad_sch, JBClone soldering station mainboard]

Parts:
C1, C6, C12, C13: 100n; C_0805_2012Metric_Pad1.18x1.45mm_HandSolder; digikey 1276-1003-1-ND
C2, C3, C7, C17: 10uF; C_0805_2012Metric_Pad1.18x1.45mm_HandSolder; digikey 1276-1096-1-ND
D1: LED; LED_0805_2012Metric_Pad1.15x1.40mm_HandSolder; digikey 1516-QBLP631-IG5CT-ND
D2, D3, D4, D5: BAT54S; SOT-23; digikey BAT54S-FDICT-ND
H1, H2, H3: MountingHole; MountingHole_3.2mm_M3; digikey N/A
J1: HMI; PinHeader_1x04_P2.54mm_Vertical; digikey 664-G800W304018EU-ND
J2, J4, J5, J10: PB_2; DaughterBoard; digikey 732-61300621821-ND
J3: USB; PinHeader_1x03_P2.54mm_Vertical; digikey 664-G800W305018EU-ND
J6: GPIO; PinSocket_2x04_P2.54mm_Vertical; digikey 732-61300621821-ND
J7: STlink; PinHeader_1x03_P2.54mm_Vertical; digikey 664-G800W305018EU-ND
J8: PWR; TerminalBlock_Phoenix_MKDS-1,5-3-5.08_1x03_P5.08mm_Horizont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; digikey 277-1264-ND
J9: STAND; PinHeader_1x03_P2.54mm_Vertical; digikey 664-G800W305018EU-ND
PS1: IRM-02-5; Converter_ACDC_MeanWell_IRM-02-xx_THT; digikey 1866-3009-ND
Q1: MMBT3904; SOT-23; digikey MMBT3904TPMSCT-ND
R1, R4, R5, R6, R7, R8, R11, R14, R15: 10k; R_0805_2012Metric_Pad1.20x1.40mm_HandSolder; digikey P10KACT-ND
R2, R3, R9, R10, R13: 1.5k; R_0805_2012Metric_Pad1.20x1.40mm_HandSolder; digikey 311-1.5KARCT-ND
R12: 100k; R_0805_2012Metric_Pad1.20x1.40mm_HandSolder; digikey P100KACT-ND
R23, R25: 590k; R_0805_2012Metric_Pad1.20x1.40mm_HandSolder; digikey P590KDACT-ND
RV1: 270KD07; RV_Disc_D7mm_W4.8mm_P5mm; digikey 13-270KD07-ND
U1: STM32F103C8T6; LQFP-48_7x7mm_P0.5mm; digikey 497-17666-1-ND
U2, U5, U6, U7: LMV321; SOT-23-5_HandSoldering; digikey 296-9567-1-ND
U3: TPS22919DCKR; SOT-23-6_Handsoldering; digikey 296-TPS22919DCKRCT-ND
U4: 24FC16T; SOT-23-5_HandSoldering; digikey 150-24FC16T-I/OTCT-ND
U10: LD1117DT33; TO-252-2; digikey 497-1235-1-ND
Y2: 8MHz; Resonator_SMD_Murata_CSTxExxV-3Pin_3.0x1.1mm_HandSoldering; digikey 490-17958-1-ND

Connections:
+3.3V: C12.1, C13.1, C17.1, J2.5, J4.5, J5.5, J6.7, J10.5, R1.1, R3.2, R9.2, R10.2, R11.1, R12.1, R14.1, R15.1, U1.9 (VDDA), U1.24 (VDD), U1.36 (VDD), U1.48 (VDD), U4.4 (V_{CC}), U5.5 (V+), U6.5 (V+), U7.5 (V+), U10.2 (VO)
+5V: C7.1, J1.1, J6.8, PS1.4 (+Vo), R5.1, R6.1, U2.5 (V+), U3.1 (VIN), U10.3 (VI)
+5VA: C3.1, J2.6, J4.6, J5.6, J10.6, U3.5 (QOD), U3.6 (VOUT)
/AC_L: J8.2 (Pin_1), PS1.2 (AC/L)
/AC_N: J8.1 (Pin_2), PS1.1 (AC/N)
/HEATER_1: J2.2, U1.46 (PB9)
/HEATER_2: J10.2, U1.45 (PB8)
/HEATER_3: J5.2, U1.43 (PB7)
/HEATER_4: J4.2, U1.42 (PB6)
/HMI_RX: J1.2, U1.31 (PA10_RX1)
/HMI_TX: J1.3, U1.30 (PA9_TX1)
/NRST: C6.1, R1.2, U1.7 (NRST)
/PA4: J6.1, U1.14 (PA4)
/PA5: J6.2, U1.15 (PA5)
/PA6: J6.3, U1.16 (PA6)
/PA7: J6.4, U1.17 (PA7)
/PA15: U1.38 (PA15)
/PB0: J6.6, U1.18 (PB0)
/SCL2: R9.1, U1.21 (PB10), U4.1 (SCL)
/SDA2: R10.1, U1.22 (PB11), U4.3 (SDA)
/STAND_1: U1.39 (PB3), U5.4
/STAND_2: U1.40 (PB4), U6.4
/STAND_3: U1.41 (PB5), U7.4
/SWCLK: J7.2, U1.37 (PA14_SWCLK)
/SWIO: J7.3, U1.34 (PA13_SWDIO)
/TEMP_1: J2.1, U1.12 (PA2)
/TEMP_2: J10.1, U1.13 (PA3)
/TEMP_3: J5.1, U1.10 (PA0)
/TEMP_4: J4.1, U1.11 (PA1)
/USB_DM: J3.3, U1.32 (PA11_USB-)
/USB_DP: J3.2, R3.1, U1.33 (PA12_USB+)
/ZERO_CROSS: J2.3, U1.29 (PA8)
/hartbeat: C1.1, U1.28 (PB15)
GND: C2.2, C3.2, C6.2, C7.2, C12.2, C13.2, C17.2, D1.1 (K), D2.3 (COM), D3.3 (COM), D4.3 (COM), D5.3 (COM), J1.4, J2.4, J2.7, J2.8, J3.1, J4.4, J4.7, J4.8, J5.4, J5.7, J5.8, J6.5, J7.1, J10.4, J10.7, J10.8, PS1.3 (-Vo), Q1.2 (E), R7.2, R8.2, R13.1, R25.1, RV1.2, U1.8 (VSSA), U1.23 (VSS), U1.35 (VSS), U1.47 (VSS), U2.2 (V-), U3.2 (GND), U4.2 (V_{SS}), U4.5 (WP), U5.2 (V-), U6.2 (V-), U7.2 (V-), U10.1 (GND), Y2.2
unnamed: C1.2, R4.2
unnamed: D1.2 (A), R2.1
unnamed: D2.2 (K), Q1.1 (B), R4.1
unnamed: D3.1 (A), D3.2 (K), J9.1, R11.2, U5.1 (+)
unnamed: D4.1 (A), D4.2 (K), J9.2, R14.2, U6.1 (+)
unnamed: D5.1 (A), D5.2 (K), J9.3, R15.2, U7.1 (+)
unnamed: J8.3, R23.2, RV1.1
unnamed: C2.1, Q1.3 (C), R5.2, U2.3 (-)
unnamed: R23.1, R25.2
unnamed: R7.1, U1.44 (BOOT0)
unnamed: U1.5 (PD0_XTAL), Y2.1
unnamed: U1.6 (PD1_XTAL), Y2.3
unnamed: R6.2, R8.1, U2.1 (+)
unnamed: R2.2, U2.4, U3.3 (ON)
unnamed: R12.2, R13.2, U5.3 (-), U6.3 (-), U7.3 (-)

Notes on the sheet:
STlink header
POWER SUPPLY
ESD safety and GND fault protection
HARTBEAT DETECTOR OUTPUT ENABLE
INTERFACES
ramp generator
USB header
HMI serial header
WP tied to VSS, normal memory operation is enabled
calibration and settings memory
INPUT: 220Vac OUTPUT1: 5Vdc @ 300mA OUTPUT2: 3.3V @ 100mA
GPIO HEADER
MCU outputs a pulse every zero cross transition. if more than one pulse is not detected heaters are disabled
EEPROM
STAND SENSE
stand raised to 0.2V from diode drop if iron pulls stand to ground (<50mV) the output goes LOW
treshold detector
power switch
MCU
HEATER MODULES

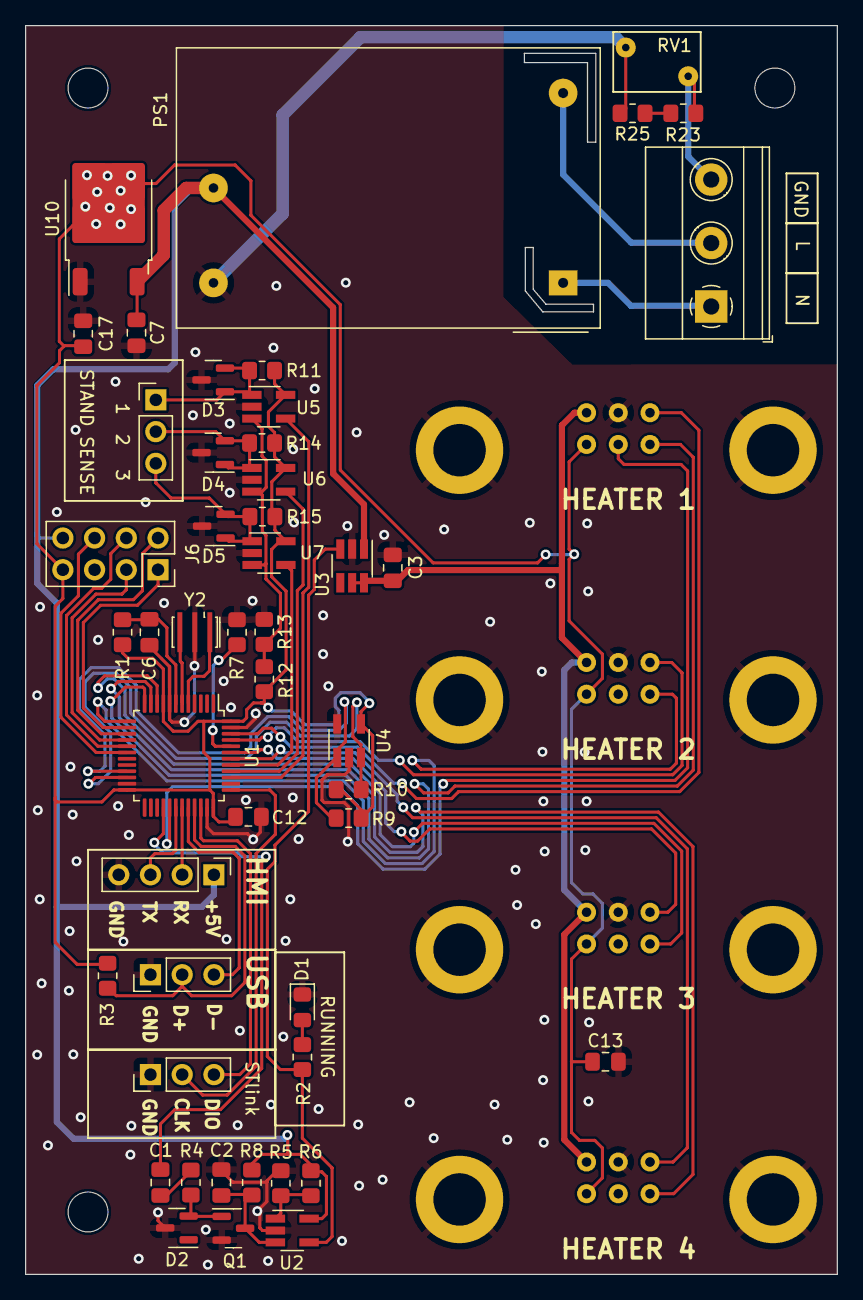
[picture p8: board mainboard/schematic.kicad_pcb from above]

Board: 2 copper layers, 65.0 x 100.0 mm, 55 parts (0 on the bottom side), 48 nets.

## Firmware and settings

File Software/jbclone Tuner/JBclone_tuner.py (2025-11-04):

import tkinter as tk
from tkinter import ttk
from tkinter import messagebox
from matplotlib import pyplot as plt
from matplotlib.backends.backend_tkagg import FigureCanvasTkAgg
from matplotlib.figure import Figure
from matplotlib.axes import Axes
import time
import serial
from serial.tools.list_ports import comports
from typing import Optional, List, Dict, Callable


class Station:
    """Represents a controller interface for a soldering station."""

    tips = {
        "T245": 0,
        "AM120-1": 1,
        "AM120-2": 2,
        "C360": 3,
    }

    class commands:
        """Command identifiers understood by the station."""

        enable = "en"
        temp_runaway = "runaway_t"
        temp_set_min = "set_min_t"
        temp_set_max = "set_max_t"
        temp_measure = "meas_t"
        temp_set = "set_t"
        tc_voltage_measure = "meas_uv"
        tc_voltage_setpoint = "set_uv"
        cal_tc_table = "tc_cal_table"
        pid_kp = "pid_kp"
        pid_ki = "pid_ki"
        pid_kd = "pid_kd"
        pid_derivative_filter_time = "pid_d_tau"
        pid_op = "pid_op"
        sleep_temp = "sleep_set_t"
        sleep_delay = "sleep_delay"
        sleep_state = "sleep_state"
        restore_default_config = "restore"

    def __init__(self):
        """Initialize station controller."""
        self.baud = 152000
        self.port: Optional[serial.Serial] = None
        self.connected = False
        self.tip_index = None
        self.tip_changed = False

    def connect(self, target_port: str) -> bool:
        """Connect to the station on the specified port."""
        try:
            if self.port is not None:
                self.disconnect()

            if target_port not in [i.name for i in list(comports())]:
                raise ValueError(f"Port {target_port} not available")

            self.port = serial.Serial(target_port, self.baud, timeout=1)

            if not self.port.is_open:
                self.disconnect()

            self.connected = True

        except Exception as e:
            self.disconnect()
            messagebox.showerror("Connection Error", str(e))

        return self.connected

    def disconnect(self) -> None:
        """Disconnect from the station and close the port."""
        if self.port is not None:
            self.port.close()
            self.port = None
            self.connected = False

    def validate_comand(self, command: str) -> None:
        """Validate a command string against known commands. raises an exception if invalid."""
        if self.port is None:
            raise Exception("Not connected to any station")

        valid_commands = [
            v for k, v in vars(self.commands).items() if not k.startswith("__")
        ]
        if command not in valid_commands:
            raise Exception(f"Invalid command: {command}")

    def set_target_tip(self, new_tip: str | int) -> bool:
        """Set the target tip index based on the provided string or integer.
        spoawns error dialog and returns false if the tip is invalid, True if good"""
        try:
            if isinstance(new_tip, int):
                self.tip_index = int(new_tip)
                if self.tip_index not in self.tips.values():
                    raise KeyError(f"Invalid tip index: {new_tip}")
            elif isinstance(new_tip, str):
                self.tip_index = self.tips[new_tip]
            else:
                raise ValueError(
                    f"Invalid tip type: {type(new_tip)}. Expected str or int."
                )
        except ValueError as e:
            messagebox.showerror("Error", str(e))
            return False
        except KeyError as e:
            messagebox.showerror("Error", str(e))
            return False
        return True

    def set(self, command: str, value=None) -> None:
        """Send a value-setting command to the station.
        shows messagebox if the response indicates failure.
        """
        try:
            self.validate_comand(command)

            command_str = f"{self.tip_index}:{command}:{value}\n"
            self.port.write(command_str.encode("ASCII"))
            response = self.port.read_until().decode().strip()

            error_preamble = "ERROR "
            if response.startswith(error_preamble):
                raise Exception(f"{command}:{response[len(error_preamble):]}")

            if response != "OK":
                raise Exception(f"Unexpected response: {response}")
        except Exception as e:
            messagebox.showerror("Unable To Set", str(e))

    def get(self, command: str, appendix=None) -> str | None:
        """Query a value from the station and return the response.
        show messagebox if response indicates failure.
        """
        try:
            self.validate_comand(command)
            arg = appendix if appendix is not None else "?"
            message = f"{self.tip_index}:{command}:{arg}"
            self.port.write(message.encode("ASCII"))
            response = self.port.read_until()
            response = response.decode().strip()

            error_preamble = "ERROR "
            if response.startswith(error_preamble):
                raise ValueError(f"{command}:{response[len(error_preamble):]}")
            return response

        except Exception as e:
            messagebox.showerror("Unable To Get", str(e))
            return None


def check_float_entry(event: tk.Event) -> bool:
    "check if the entry is a valid float and change color accordingly"
    try:
        float(event.widget.get())
        event.widget.config(bg="white")
        return True
    except ValueError:
        event.widget.config(bg="red")
        return False


def update_entry_value(entry: tk.Entry, value: float | str, digits: int = 2) -> None:
    "updates the entry with a float value, formatted to the specified number of digits is not selected"
    try:
        if entry.focus_get() == entry:
            return

        output: str = ""
        if isinstance(value, str):
            try:
                parsed_float = float(value)
                output = f"{parsed_float:.{digits}f}"
            except ValueError:
                output = value

        elif isinstance(value, (int, float)):
            output = f"{value:.{digits}f}"

        entry.delete(0, tk.END)
        entry.insert(0, output)
    except Exception as e:
        print(f"Error updating entry: {e}")


def bind_defaults_to_entry(
    escape_focus_target: tk.Widget,
    entry: tk.Entry,
    return_func: Optional[Callable[[tk.Event], None]] = None,
) -> None:
    """
    Bind default behavior to a tk.Entry widget.

    - <Return>: Triggers the given callback, if provided.
    - <Escape>: Restores focus to the parent widget.
    - <KeyRelease>: Runs real-time float validation (check_float_entry).

    Args:
        parent: The parent widget to focus when Escape is pressed.
        entry: The entry widget to bind events to.
        return_func: An optional function to call on Return key.
    """
    entry.bind("<KeyRelease>", check_float_entry)
    entry.bind("<Escape>", lambda e: escape_focus_target.focus_set())
    if return_func is not None:
        entry.bind(
            "<Return>", lambda e: (return_func(e), escape_focus_target.focus_set())
        )


def labeled_entry(
    parent: tk.Widget,
    callback: Optional[Callable[[tk.Event], None]],
    row: int,
    column: int,
    label_text: Optional[str] = None,
    escape_focus_target: Optional[tk.Widget] = None,
) -> tk.Entry:
    """Create a labeled entry field with a callback for the Return key.

    - <Return>: Triggers the given callback, if provided.
    - <Escape>: Restores focus to the parent widget.
    - <KeyRelease>: Runs real-time float validation (check_float_entry).

    Args:
        parent: Parent widget where the entry is placed.
        label_text: Text to display next to the entry field.
        callback: Function to call when the Return key is pressed.
        row: Row index in the grid.
        column: Column index in the grid
        escape_focus_target: Widget to focus when Escape is pressed.
    Returns:
        The created tk.Entry instance.
    """
    if label_text is not None:
        label = tk.Label(parent, text=label_text, bg="lightgray", width=15)
        label.grid(row=row, column=column, padx=2, pady=2, sticky="e")
        column = column + 1
    field = tk.Entry(parent, width=15)
    field.grid(row=row, column=column, padx=2, pady=2, sticky="w")
    bind_defaults_to_entry(
        escape_focus_target=(
            parent if escape_focus_target is None else escape_focus_target
        ),
        entry=field,
        return_func=callback,
    )
    return field


def readout_label(
    parent: tk.Widget,
    row: int,
    column: int,
    label_text: str = "---",
) -> tk.Label:
    """Create a label and a corresponding readout display.
    Args:
        parent: Parent widget where the label is placed.
        label_text: Text to display next to the readout field.
        row: Row index in the grid.
        column: Column index in the grid.
    Returns:
        The created tk.Label instance for the readout."""
    label = tk.Label(parent, text=label_text, bg="lightgray", width=15)
    label.grid(row=row, column=column, padx=2, pady=2, sticky="e")
    readout = tk.Label(parent, text="---", bg="lightgray", width=15)
    readout.grid(row=row, column=column + 1, padx=2, pady=2, sticky="w")
    return readout


def button(
    parent: tk.Widget,
    text: str,
    row: int,
    column: int,
    command: Callable[[tk.Event], None],
    state="normal",
) -> tk.Button:
    """
    Create a button with a label and attach it to a grid location.

    Args:
        parent: Parent widget where the button is placed.
        text: Label text shown on the button.
        row: Row index in the grid.
        column: Column index in the grid.
        command: Function to call when the button is pressed.
    Returns:
        The created tk.Button instance.
    """
    btn = tk.Button(parent, text=text, width=15, state=state)
    btn.grid(row=row, column=column, padx=2, pady=2, sticky="e")
    btn.config(command=command)
    return btn


def send_value(parent: tk.Widget, param: str, event: tk.Event | None) -> None:
    """Attempt to send the value from the event to the station. Show error on failure."""
    try:
        parent.focus_set()
        new_value = float(event.widget.get())
        station.set(param, new_value)
    except ValueError:
        messagebox.showerror("Invalid Value", f"Invalid value: {event.widget.get()}")


class PlotData:
    """Stores and manages historical data for plotting"""

    def __init__(self, length: int) -> None:
        """Initialize the data lists with a specified length."""
        self.length: int = length
        self.reset()

    def reset(self) -> None:
        """Reset all data lists to their initial state."""
        self.sp: List[float] = [0.0] * self.length
        self.pv: List[float] = [0.0] * self.length
        self.op: List[float] = [0.0] * self.length
        self.t: List[float] = [0.0] * self.length

    def append(self, pv: float, sp: float, op: float, t: float) -> None:
        """Append new data points to the lists, maintaining the specified length."""
        for attr, val in zip((self.sp, self.pv, self.op, self.t), (sp, pv, op, t)):
            attr.append(val)
            if len(attr) > self.length:
                attr.pop(0)

    def set_length(self, new_length: int) -> None:
        """Set a new length for the data lists, trims or append zeros to fill"""
        if new_length > 0:
            for attr in (self.sp, self.pv, self.op, self.t):
                if new_length > self.length:
                    attr[:0] = [0.0] * (new_length - self.length)
                else:
                    del attr[:-new_length]
            self.length = new_length


class PlotFrame:
    """Creates and updates the plot canvas embedded in a tkinter Frame."""

    def __init__(self, parent: tk.Widget) -> None:
        # plot frame returned
        self.frame = tk.Frame(parent, bg="white", relief="solid", bd=1)
        self.frame.grid(row=0, column=0, sticky="nsew", padx=(5, 10), pady=10)
        self.frame.columnconfigure(0, weight=1)
        self.frame.rowconfigure(0, weight=1)

        # build plot
        fig = Figure()
        self.axis_pv_sp: Axes = fig.add_subplot(111)
        self.axis_pv_sp.set_xlabel("Time [s]")
        self.axis_pv_sp.set_ylabel("PV / SP")
        self.axis_pv_sp.grid()

        self.axis_op: Axes = self.axis_pv_sp.twinx()
        self.axis_op.set_ylabel("OP", color="blue")
        self.axis_op.tick_params(axis="y", colors="blue")

        def create_line(ax: Axes, label: str, color: str) -> plt.Line2D:
            (line,) = ax.plot([], [], label=label)
            line.set_color(color)
            return line

        self.lines: Dict[str, plt.Line2D] = {
            "sp": create_line(self.axis_pv_sp, "Set", "green"),
            "pv": create_line(self.axis_pv_sp, "Meas", "red"),
            "op": create_line(self.axis_op, "Out", "blue"),
        }

        # build canvas on frame
        self.canvas = FigureCanvasTkAgg(fig, master=self.frame)
        self.canvas_widget = self.canvas.get_tk_widget()
        self.canvas_widget.grid(row=0, column=0, sticky="nsew")

    def set_plot_data(self, data: PlotData, limits: Dict[str, float]) -> None:
        """Update the plot with new data and adjust the axes limits.

        Args:
            data (PlotData): The data object containing the time, setpoint, process variable, and output values.
            limits (Dict[str, float]): ['pvsp_min', 'pvsp_max', 'op_min', 'op_max']
        """
        self.lines["sp"].set_data(data.t, data.sp)
        self.lines["pv"].set_data(data.t, data.pv)
        self.lines["op"].set_data(data.t, data.op)

        self.axis_pv_sp.set_ylim(limits["pvsp_min"], limits["pvsp_max"])
        self.axis_op.set_ylim(limits["op_min"], limits["op_max"])

        self.axis_pv_sp.relim()
        self.axis_op.relim()
        self.axis_pv_sp.autoscale_view()
        self.axis_op.autoscale_view()
        self.canvas.draw()


class PlotController:
    """Handles the logic for updating and configuring a real-time data plot."""

    def __init__(self, parent: tk.Widget) -> None:
        self.parent = parent
        self.data = PlotData(length=100)  # default length
        self.plot = PlotFrame(parent)

        self.scan_rate: int = 200
        self.limits: Dict[str, float] = {
            "pvsp_min": 0.0,
            "pvsp_max": 500.0,
            "op_min": 0.0,
            "op_max": 1.0,
        }

    def apply_default_scale(self, mode: str) -> None:
        """Set the default scale for the plot based on the mode (Temperature or Voltage)."""
        if mode == "T":
            self.limits["pvsp_min"] = 0
            self.limits["pvsp_max"] = 500
            self.plot.axis_pv_sp.set_ylabel("PV / SP [C°]")
        elif mode == "V":
            self.limits["pvsp_min"] = 0
            self.limits["pvsp_max"] = 10000
            self.plot.axis_pv_sp.set_ylabel("PV / SP [uV]")

    def write_data_to_plot(self) -> None:
        """Update the plot with the current data and limits."""
        self.plot.set_plot_data(self.data, self.limits)

    def append_data_point(self, sp: float, pv: float, op: float, t: float) -> None:
        """Append a new data point to the plot and update the display."""
        self.data.append(pv, sp, op, t)
        self.write_data_to_plot()

    def reset(self) -> None:
        """Reset the plot data and clear the display."""
        self.data.reset()
        self.write_data_to_plot()

    def get_frame(self) -> tk.Frame:
        """Return the frame containing the plot."""
        return self.plot.frame

    def open_config_window(self) -> None:
        """Open a configuration window for setting plot parameters."""
        config_window = tk.Toplevel(self.plot.frame)
        config_window.title("Plot Configuration")

        # Create all entry widgets first (do NOT populate yet)
        record_length_entry = labeled_entry(
            config_window,
            label_text="Points:",
            callback=lambda e: check_and_apply(),
            row=0,
            column=0,
        )

        scan_rate_entry = labeled_entry(
            config_window,
            label_text="Scan Rate [ms]:",
            callback=lambda e: check_and_apply(),
            row=1,
            column=0,
        )

        pvsp_limit_min_entry = labeled_entry(
            config_window,
            label_text="PV/SP Y (min/max):",
            callback=lambda e: check_and_apply(),
            row=2,
            column=0,
        )

        pvsp_limit_max_entry = labeled_entry(
            config_window,
            label_text=None,
            callback=lambda e: check_and_apply(),
            row=2,
            column=2,
        )

        op_limit_min_entry = labeled_entry(
            config_window,
            label_text="OP Y (min/max):",
            callback=lambda e: check_and_apply(),
            row=3,
            column=0,
        )

        op_limit_max_entry = labeled_entry(
            config_window,
            label_text=None,
            callback=lambda e: check_and_apply(),
            row=3,
            column=2,
        )

        def check_and_apply() -> None:
            """Check the entries and apply the values if valid."""
            entries = {
                "Record Length": (record_length_entry.get(), int),
                "Scan Rate": (scan_rate_entry.get(), int),
                "PV-SP min": (pvsp_limit_min_entry.get(), float),
                "PV-SP max": (pvsp_limit_max_entry.get(), float),
                "OP min": (op_limit_min_entry.get(), float),
                "OP max": (op_limit_max_entry.get(), float),
            }

            try:
                parsed = {key: cast(val) for key, (val, cast) in entries.items()}
            except ValueError:
                return  # skip apply if any value fails

            self.data.set_length(parsed["Record Length"])
            self.scan_rate = parsed["Scan Rate"]
            self.limits.update(
                {
                    "pvsp_min": parsed["PV-SP min"],
                    "pvsp_max": parsed["PV-SP max"],
                    "op_min": parsed["OP min"],
                    "op_max": parsed["OP max"],
                }
            )

            config_window.destroy()

        # Set focus explicitly to the config window (important!)
        config_window.focus_set()

        # Now safely update entries after window has the focus
        update_entry_value(record_length_entry, self.data.length, digits=0)
        update_entry_value(scan_rate_entry, self.scan_rate, digits=0)
        update_entry_value(pvsp_limit_min_entry, self.limits["pvsp_min"], digits=0)
        update_entry_value(pvsp_limit_max_entry, self.limits["pvsp_max"], digits=0)
        update_entry_value(op_limit_min_entry, self.limits["op_min"], digits=2)
        update_entry_value(op_limit_max_entry, self.limits["op_max"], digits=2)

        # Add Apply / Cancel buttons
        tk.Button(config_window, text="Apply", command=check_and_apply).grid(
            row=5, column=1, padx=5, pady=10, sticky="ew"
        )
        tk.Button(config_window, text="Cancel", command=config_window.destroy).grid(
            row=5, column=2, padx=5, pady=10, sticky="ew"
        )
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

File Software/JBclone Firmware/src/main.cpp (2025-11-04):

#include <Arduino.h>
#include "Hardware.h"
#include "objects.h"
#include "zero_cross.h"
#include "hartbeat.h"
#include "Serial_controls.h"
#include "display.h"

void setup()
{

    // pheripheral init
    _serial_usb.begin(_serial_usb_baud);
    _serial_usb.setTimeout(_serial_usb_timeout);

    i2cBus.begin();

    _hmi.init(_serial_hmi_baud, _serial_hmi_timeout);

    // board init
    analogReadResolution(ADC_BITS);
    attachInterrupt(digitalPinToInterrupt(_pin_zero_cross), zero_cross_isr, RISING);
    pinMode(_pin_hartbeat, OUTPUT);
    hartbeat_set();

    // heaters init
    for (int i = 0; i < _heater_count; i++)
        heaters[i].init();
}

void loop()
{
    // hartbear routine
    update_hartbeat();

    // heater update
    for (int i = 0; i < _heater_count; i++)
    {
        heaters[i].update();
    }

    // interfaces
    String message;
    String response;

    if (_serial_usb.available() > 0)
    {
        message = _serial_usb.readStringUntil(_serial_usb_terminator);
        bool success = eval_serial_command(message, response);

        if (!success)
            _serial_usb.print("ERROR ");

        if (response.length())
            _serial_usb.print(response);

        if (!success || response.length() > 0)
            _serial_usb.print(_serial_usb_terminator);
    }

    bool hmi_message = _hmi.read(message);
    if (hmi_message)
    {
        eval_serial_command(message, response);
    }
}

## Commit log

2026-01-09 added PDF print of schematic
2026-01-09 added PDF of schematic
